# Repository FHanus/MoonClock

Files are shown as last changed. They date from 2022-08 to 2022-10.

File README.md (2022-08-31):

## MoonClock C version

MoonClock website - https://moonclock.com

This fork is translation of the original app into smoother C language.

## You have received and unboxed your MoonClock. Congratulations!

What now?

1. Power your MoonClock.

2. On any device, open Wi-Fi connections and you should see "MoonClock Configuration" access point, tap it and a website should open. If a website doesn't open, open browser and enter "192.168.4.1" in the address bar.

3. Set up a Wi-Fi connection and if you want to, edit any of the settings in the main tab and then press update.

That's all!

## Want more to know all the possible options?

* app_choice
```sh
BlockHeight \ CryptoApp \ Difficulty \ Fees \ Halving \ MarketCap \ MoscowTimeApp \ TimeApp
```
* crypto_choice
```sh
cardano \ algorand \ baked-token \ bitcoin \ chain \ dogecoin \ ethereum \ kusama \ litecoin \ polkadot \ thorchain \ verasity
```
* fiat_choice
```sh
eur \ gbp \ usd
```
* timezone_choice
```sh
https://sites.google.com/a/usapiens.com/opnode/time-zones
```
* contrast_after_sunrise_choice 
```sh
0 - 255
```
* contrast_after_sunset_choice
```sh
0 - 255
```
* hide_seconds
```sh
true \ false
```

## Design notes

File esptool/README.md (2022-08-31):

## MoonClock firmware updater

1. Download and unzip the "moonclock_code_updater.zip" file

2. Open "HELP_ME" file and edit the necessary parts of the command. Mainly the path names and the port (note that it can change during upload as the device restarts). 

3. Copy the command and paste it into terminal

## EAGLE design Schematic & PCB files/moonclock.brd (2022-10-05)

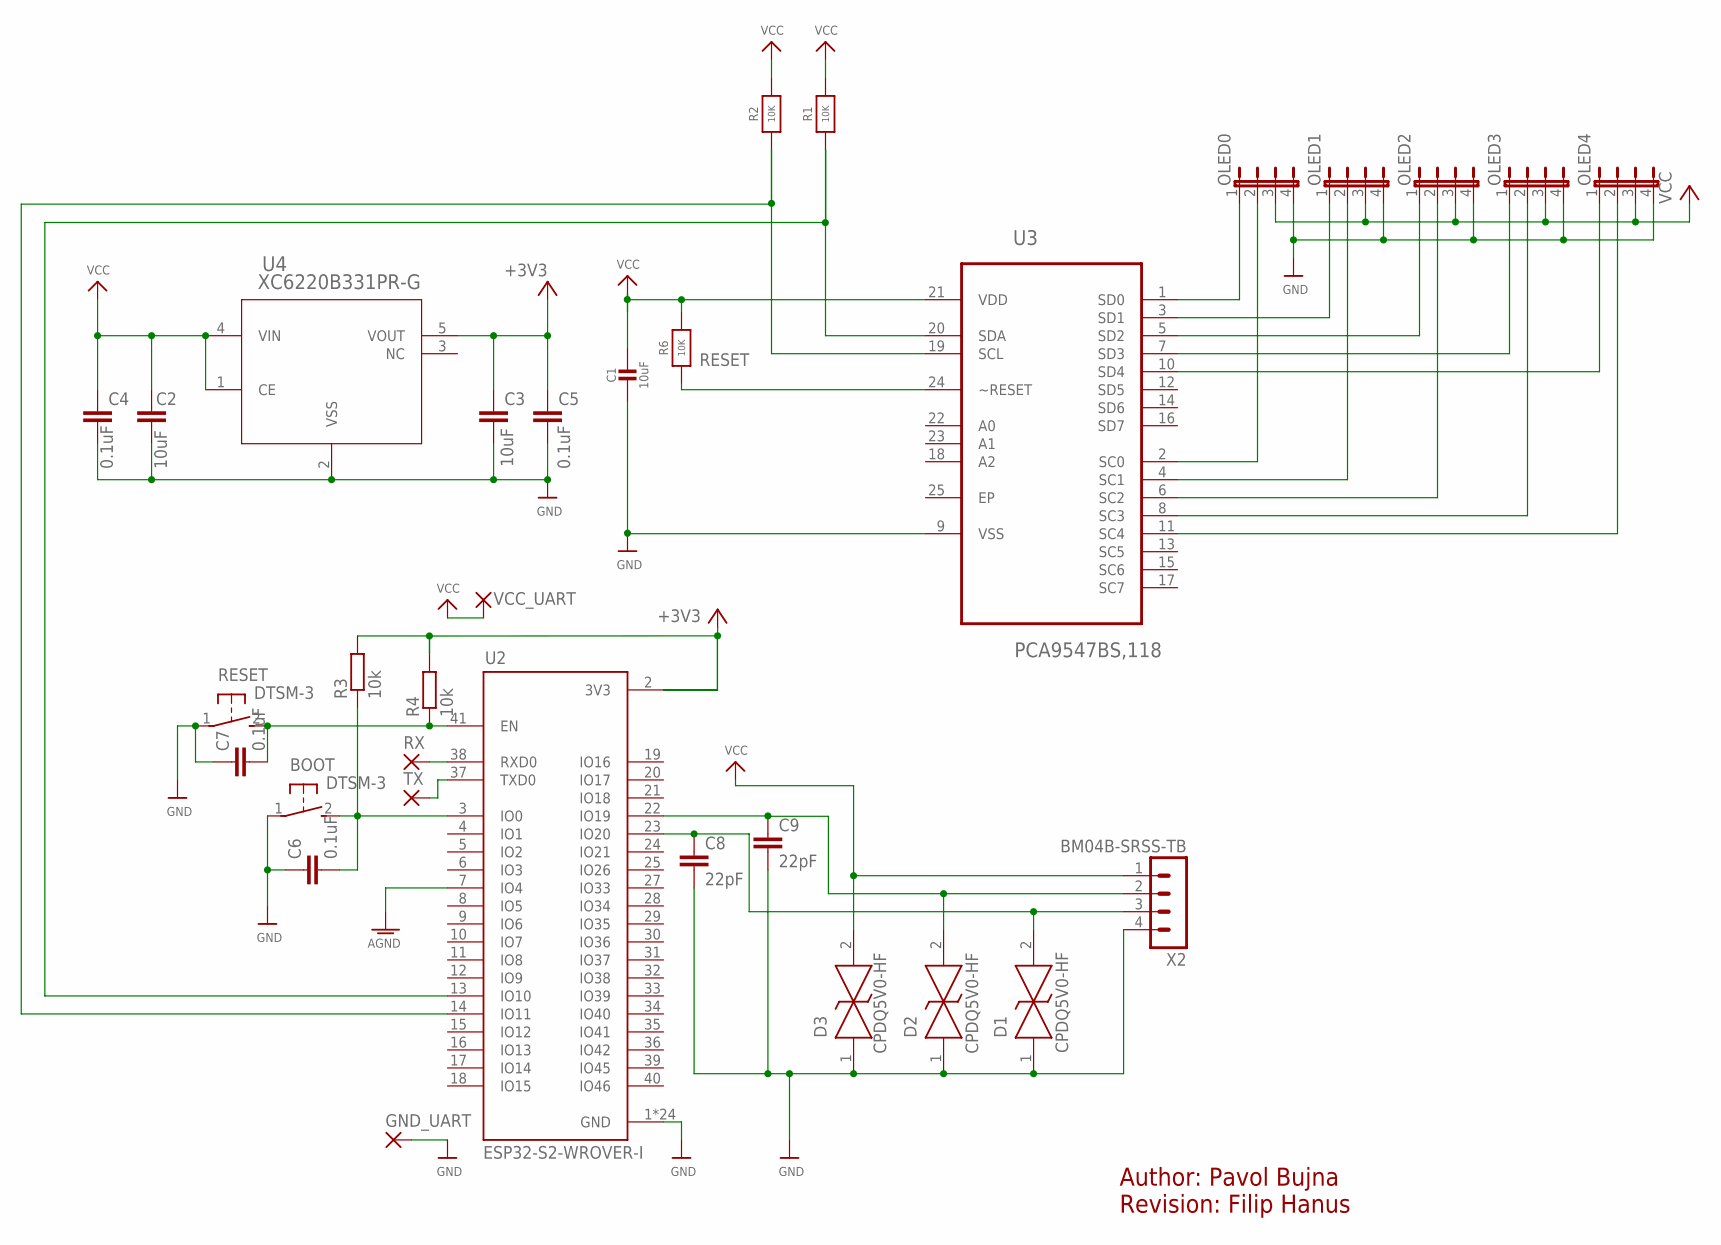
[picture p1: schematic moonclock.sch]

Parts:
BOOT: DTSM-3
C1: 10uF; 0805-NO
C2, C3: 10uF; C0805
C4, C5, C6, C7: 0.1uF; C0805
C8, C9: 22pF; C0805
D1, D2, D3: CPDQ5V0-HF; MBTB-D-SOD-923F-IMP-0402
GND_UART: SMD2; SMD1,27-2,54
OLED0, OLED1, OLED2, OLED3, OLED4: JP4E; JP4
R1, R2: 10K; 0805-NO
R3, R4: 10k; R0805
R6: 10K; _0805MP
RESET: DTSM-3
RX: SMD2; SMD1,27-2,54
TX: SMD2; SMD1,27-2,54
U2: ESP32-S2-WROVER-I
U3: PCA9547BS,118; QFN50P400X400X100-25N
U4: XC6220B331PR-G; SOT-89-5_TOR
VCC_UART: SMD2; SMD1,27-2,54
X2: BM04B-SRSS-TB

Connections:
+3V3: C3.1, C5.1, R3.2, R4.2, U4.5 (VOUT)
AGND: U2.7 (IO4)
D+: C8.1, D1.2 (A), U2.23 (IO20), X2.3
D-: C9.1, D2.2 (A), U2.22 (IO19), X2.2
GND: BOOT.1, C1.2, C2.2, C3.2, C4.2, C5.2, C6.1, C7.1, C8.2, C9.2, D1.1 (K), D2.1 (K), D3.1 (K), GND_UART.1, OLED0.4, OLED1.4, OLED2.4, OLED3.4, OLED4.4, RESET.1, U2.1 (GND), U2.26 (GND), U2.42 (GND), U2.43.1 (GND), U2.43.2 (GND), U2.43.3 (GND), U2.43.4 (GND), U2.43.5 (GND), U2.43.6 (GND), U2.43.7 (GND), U2.43.8 (GND), U2.43.9 (GND), U2.43.10 (GND), U2.43.11 (GND), U2.43.12 (GND), U2.43.13 (GND), U2.43.14 (GND), U2.43.15 (GND), U2.43.16 (GND), U2.43.17 (GND), U2.43.18 (GND), U2.43.19 (GND), U2.43.20 (GND), U2.43.21 (GND), U3.9 (VSS), U4.2 (VSS), X2.4
unnamed: R1.1, U2.13 (IO10), U3.20 (SDA)
unnamed: R2.1, U2.14 (IO11), U3.19 (SCL)
unnamed: OLED0.1, U3.1 (SD0)
unnamed: TX.1, U2.37 (TXD0)
unnamed: RX.1, U2.38 (RXD0)
unnamed: OLED1.1, U3.3 (SD1)
unnamed: BOOT.2, C6.2, R3.1, U2.3 (IO0)
unnamed: OLED2.1, U3.5 (SD2)
unnamed: C7.2, R4.1, RESET.2, U2.41 (EN)
unnamed: OLED3.1, U3.7 (SD3)
unnamed: OLED4.1, U3.10 (SD4)
unnamed: OLED0.2, U3.2 (SC0)
unnamed: OLED1.2, U3.4 (SC1)
unnamed: OLED2.2, U3.6 (SC2)
unnamed: OLED3.2, U3.8 (SC3)
unnamed: OLED4.2, U3.11 (SC4)
RESET: R6.1, U3.24 (~RESET)
VCC: C1.1, C2.1, C4.1, D3.2 (A), OLED0.3, OLED1.3, OLED2.3, OLED3.3, OLED4.3, R1.2, R2.2, R6.2, U3.21 (VDD), U4.1 (CE), U4.4 (VIN), VCC_UART.1, X2.1

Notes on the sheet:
Author: Pavol Bujna Revision: Filip Hanus

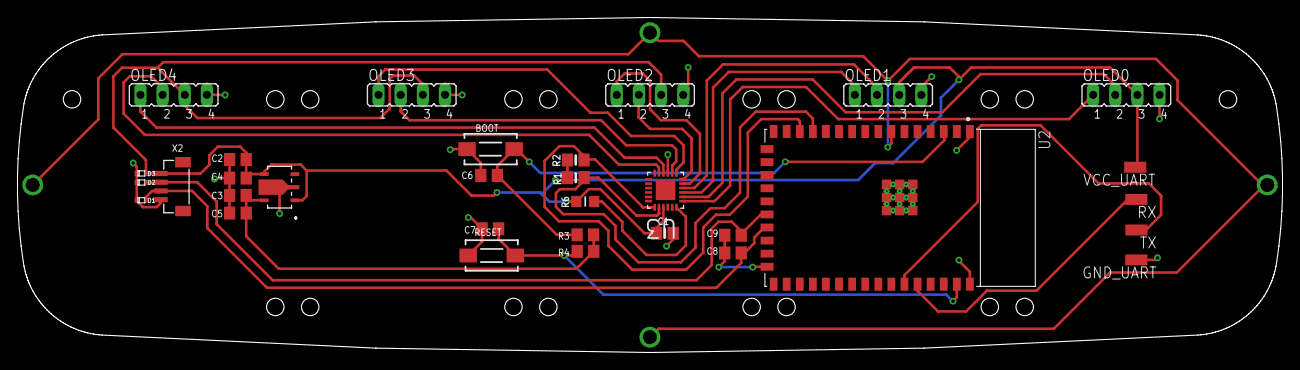
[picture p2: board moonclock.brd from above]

Board: 2 copper layers, 145.0 x 38.4 mm, 32 parts (0 on the bottom side), 22 nets.

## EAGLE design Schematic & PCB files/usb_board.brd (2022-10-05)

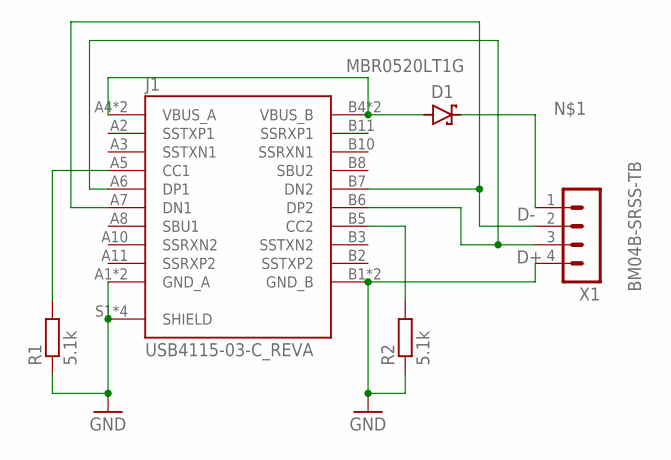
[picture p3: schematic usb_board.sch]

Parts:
D1: MBR0520LT1G; SODFL3718X115
J1: USB4115-03-C_REVA; GCT_USB4115-03-C_REVA
R1, R2: 5.1k; R0805
X1: BM04B-SRSS-TB

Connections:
D+: J1.A6 (DP1), J1.B6 (DP2), X1.3
D-: J1.A7 (DN1), J1.B7 (DN2), X1.2
GND: J1.A1 (GND_A), J1.A12 (GND_A), J1.B1 (GND_B), J1.B12 (GND_B), J1.S1 (SHIELD), J1.S2 (SHIELD), J1.S3 (SHIELD), J1.S4 (SHIELD), R1.1, R2.1, X1.4
unnamed: D1.1 (C), X1.1
unnamed: J1.A5 (CC1), R1.2
unnamed: J1.B5 (CC2), R2.2
VCC: D1.2 (A), J1.A4 (VBUS_A), J1.A9 (VBUS_A), J1.B4 (VBUS_B), J1.B9 (VBUS_B)

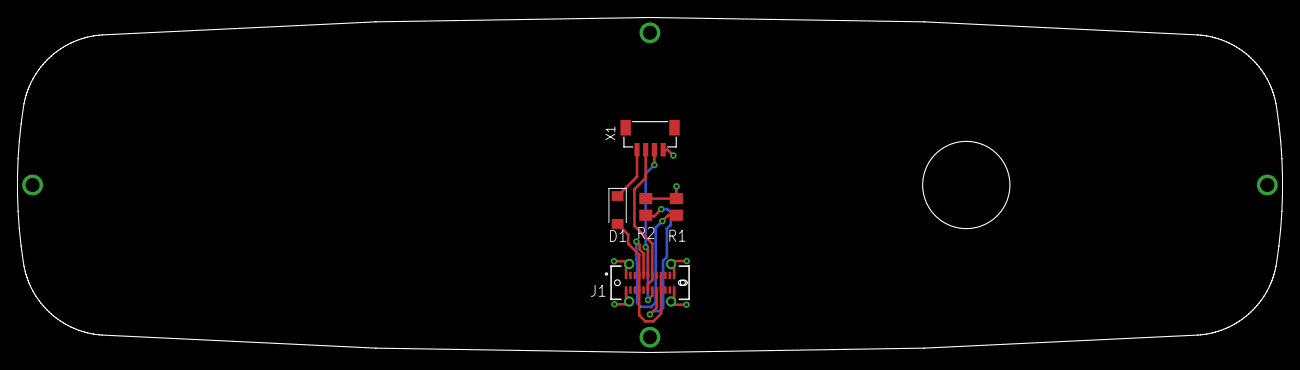
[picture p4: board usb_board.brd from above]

Board: 2 copper layers, 145.0 x 38.4 mm, 5 parts (0 on the bottom side), 7 nets.

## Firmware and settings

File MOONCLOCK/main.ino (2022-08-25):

/* MAIN.INO

   Runs all the initializations and then runs the main function in repeat
   Revision: Filip Hanus, 25/08/2022
*/

// Include file with all the library and file initializations
#include "setup.h"

// Include file with all the utility functions
#include "utils.h"

// Inlude file with all the apps
#include "apps.h"

// Setup
void setup() {
  // Startup
  if (DEBUG)
    Serial.begin(115200);
    Serial.println("Starting");
    
  vTaskDelay(500 / portTICK_PERIOD_MS);
  
  WiFi.mode(WIFI_STA);

  // Debug info
  if (DEBUG)
    Serial.println("Setting up NTP");
  
  // config time ntp server
  sntp_servermode_dhcp(1);
  configTzTime(timezone_choice, ntpServer1, ntpServer2);

  // Debug info
  if (DEBUG)
    Serial.println("Setting up displays");
  
  // Setup displays
  setupdisplays();

  // Clear displays
  displays_clear();
  displays_fill("wifi");

  // Debug info
  if (DEBUG)
    Serial.println("Starting config manager");

  // Connect to Wi-Fi
  run_config_manager();

  // Wait for the selected amount of miliseconds
  vTaskDelay(1000 / portTICK_PERIOD_MS);

  // Set contrast
  AutoContrastApp();

  // Clear displays
  displays_clear();
}

// Main loop
void loop() {
  // Run AutoContrast app every hour
  if (millis() - lastMillis >= 3600 * 1000) { //3600*1000
    lastMillis = millis();
    AutoContrastApp();
  }

  // If WiFi connects run the selected app
  if ((WiFi.status() == WL_CONNECTED)){
    App_Selector();}
  else{
    displays_fill("cross");
  }
}

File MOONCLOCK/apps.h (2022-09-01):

/* APPS.H
 * 
 * Contains all the functions for the apps
 * Revision: Filip Hanus, 25/08/2022
 */

/* App: AutoContrastApp
 * Required: setContrast, set_contrast, get_time, get_risetimes (helper functions)
 * Inputs: String timezone, int contrast_after_sunrise, int contrast_after_sunset,String latitude,String longitude
 * 
 * Functionality: Auto sets contrast of the displays
 * Revision: Filip Hanus, 16/08/2022
 */

void setContrast(Adafruit_SSD1306 *display,int index, uint8_t contrast)
// Set contrast for a selected display
{   
  // Select the display using the multiplexer
  TCA9548A(index);
  // Access contrast settings for the specific display and change it
  display->ssd1306_command(SSD1306_SETCONTRAST);
  display->ssd1306_command(contrast);
}

void set_contrast(int contrast)
// Call the set display function for all the displays
{ 
  setContrast(&display1,1, contrast);
  setContrast(&display2,2, contrast);
  setContrast(&display3,3, contrast);
  setContrast(&display4,4, contrast);
  setContrast(&display5,5, contrast);
}

String get_time(String timezone)
// Obtain time using the HTTP request, returns a string variable
{
  // Create a structure to store time data in
  struct tm timeinfo;

  // Obtain time data
  while(!getLocalTime(&timeinfo)){
    Serial.println("No time available (yet)");
    //return "00:00:00";
  }

  // Format time data
  char currenttime[10];
  strftime(currenttime,10, "%H:%M:%S", &timeinfo);
  vTaskDelay(500 / portTICK_PERIOD_MS);
  // Return current time
  return currenttime;
}

String get_risetimes(String latitude = "50.073611",String longitude = "14.435664",bool return_option=false)
// Obtain sunrise and sunset times for the specified latitude and longitude
{
  // Setup request url and request data
  String request_url = ("http://api.sunrise-sunset.org/json?lat="+latitude+"&lng="+longitude+"&date=today&formatted=0");

  // Create a json variable for the data
  const size_t sized_buffer = JSON_OBJECT_SIZE(2) + 2 * JSON_OBJECT_SIZE(6) + 150;
  DynamicJsonDocument doc(sized_buffer);
  
  // Request data
  String payload = request_data(request_url);

  // Process the requested data
  const char* json_data = payload.c_str();
  deserializeJson(doc, json_data);
 
  String sunrise = doc["results"]["sunrise"];
  String sunset = doc["results"]["sunset"];

  String sunrise_time = String(String(sunrise[11])+String(sunrise[12]));
  String sunset_time = String(String(sunset[11])+String(sunset[12]));

  // Return sunrise and sunset data
  if(return_option==false){
    return sunrise_time;
  }
  else if(return_option==true){
    return sunset_time;
  }
  else{
    return "00";
  }
}

void AutoContrastApp()
// Setup display contrast automatically
{
  // If TERMINAL output is allowed then print out status message
  if(DEBUG)
    Serial.print("Running autocontrast");
  
  String timestamp = get_time(timezone_choice);
  String stamp = String(timestamp[0])+String(timestamp[1]);
  String sunrise_time = get_risetimes(latitude_choice,longitude_choice,false);
  String sunset_time = get_risetimes(latitude_choice,longitude_choice,true);

  // If TERMINAL output is allowed then print out status message
  if(DEBUG)
    Serial.print("Sunset: ");
    Serial.print(sunset_time.toInt());
    Serial.print("Sunrise: ");
    Serial.print(sunrise_time.toInt());
    Serial.print("Time: ");
    Serial.print(stamp.toInt());
    Serial.print("\n");

  // Set after sunset contrast if the sunset hour is smaller than the current hour
  if (sunset_time.toInt() <= stamp.toInt()){
    set_contrast(contrast_after_sunset_choice);

    
    // If TERMINAL output is allowed then print out status message
    if(DEBUG)
      Serial.print("changing contrast after sunset");
  }
  // Set after sunrise contrast if the sunrise hour is smaller than the current hour
  else if (sunrise_time.toInt() <= stamp.toInt()){
    set_contrast(contrast_after_sunrise_choice);

    // If TERMINAL output is allowed then print out status message
    if(DEBUG)  
      Serial.print("changing contrast after sunrise");
  }
  // Wait for the selected time duration, note that every API has a limit to the amount of requests per minute
  vTaskDelay((100) / portTICK_RATE_MS);
} 

/* App: BlockHeight
 * Required: display_BlockHeight (helper function)
 * 
 * Functionality: Displays current block height
 * Revision: Filip Hanus, 16/08/2022
 */

void display_BlockHeight(String blockheight)
// Display the blockheight data on the displays
{
  // Process the blockheight data and split it for the display positions
  String D6 = String(blockheight[0]);
  String D5 = String(blockheight[1]);
  String D4 = String(blockheight[2]);
  String D3 = String(blockheight[3]);
  String D2 = String(blockheight[4]);
  String D1 = String(blockheight[5]);

  // Display each one of the characters on each one of the displays
  TCA9548A(1);
  display1.clearDisplay();
  display_draw_bitmap(&display1,1,bitmap_selector("chain"),"mid_wide");
  display1.display();
  
  TCA9548A(2);
  display2.clearDisplay();
  display_draw_bitmap(&display2,2,bitmap_selector(D1),"left");
  display_draw_bitmap(&display2,2,bitmap_selector(D2),"right");
  display2.display(); 
  
  TCA9548A(3);
  display3.clearDisplay();
  display_draw_bitmap(&display3,3,bitmap_selector(D3),"left");
  display_draw_bitmap(&display3,3,bitmap_selector(D4),"right");
  display3.display();
  
  TCA9548A(4);
  display4.clearDisplay();
  display_draw_bitmap(&display4,4,bitmap_selector(D5),"left");
  display_draw_bitmap(&display4,4,bitmap_selector(D6),"right");
  display4.display();
  
  TCA9548A(5);
  display5.clearDisplay();
  display_draw_bitmap(&display5,5,bitmap_selector("bitcoin"),"mid_wide");
  display5.display();
}

void BlockHeight()
// Obtain blockheight data and display it on the displays
{
  // Setup request url
  String request_url = ("https://mempool.space/api/blocks/tip/height");
  
  // Create a json variable for the data
  const size_t sized_buffer = JSON_OBJECT_SIZE(2) + 2 * JSON_OBJECT_SIZE(6) + 150;
  DynamicJsonDocument doc(sized_buffer);
  
  // Request data
  String payload = request_data(request_url);
  
  // Process the requested data
  const char* json_data = payload.c_str();

  if(DEBUG)
    Serial.print("Block Height: ");
    Serial.println(json_data);
    
  
  // Display the block height
  display_BlockHeight(json_data);

  // Wait for the selected time duration, note that every API has a limit to the amount of requests per minute
  vTaskDelay(1500 / portTICK_PERIOD_MS);
}

/* App: CryptoApp
 * Required: display_price (helper function)
 * Input: String selected_coin,String selected_fiat
 * 
 * Functionality: Displays current price
 * Revision: Filip Hanus, 16/08/2022
 */
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

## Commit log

2022-08-12 Fixing up and polishing the code
    Full release preparations. Adding comments, fixing up debug messages, clearing functions for utils
    [main.ino]
2022-08-25 Fix timeout caused by short password
    [main.ino, setup.h]
2022-08-31 Finished firmware, debugged
    * Fixed a couple of issues with the runtime
    * Created software update tool
    [apps.h]
2022-09-04 Updated EAGLE files
    [moonclock.brd, moonclock.sch, usb_board.brd]
2022-10-05 PCB
    feat: MoonClock add schematics and pcb files
    [moonclock.brd, moonclock.sch, usb_board.brd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]

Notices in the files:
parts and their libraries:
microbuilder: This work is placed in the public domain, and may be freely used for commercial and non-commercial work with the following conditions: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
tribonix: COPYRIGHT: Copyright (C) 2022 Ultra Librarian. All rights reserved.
